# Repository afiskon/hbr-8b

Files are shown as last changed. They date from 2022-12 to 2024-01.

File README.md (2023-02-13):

# HBR/8B

All HF bands QRP CW transceiver. This is an improved version of [HBR/3B](https://github.com/afiskon/hbr-3b).

* Covers 80, 40, 30, 20, 17, 15, 12 and 10 meters
* Classical single IF superheterodyne design
* Has just a few barely hearable (~S0) spurious signals
* Simple but effective AGC
* Supports RIT and XIT
* 10-30 WPM Elekey-B type keyer + straight key mode
* Keyer supports record and playback, programmable with paddles
* ~5W class C power amplifier
* Has a S-meter and a SWR meter
* Open-source firmware, schematic and 3D-printable enclosure

Links:

* Article (in Russian): https://eax.me/hbr-8b-transceiver/
* Demo: https://www.youtube.com/watch?v=GlcS9r8nLz4

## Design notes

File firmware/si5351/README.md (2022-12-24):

# stm32-si5351

HAL-based Si5351 driver for STM32.

Main respository: https://github.com/afiskon/stm32-si5351

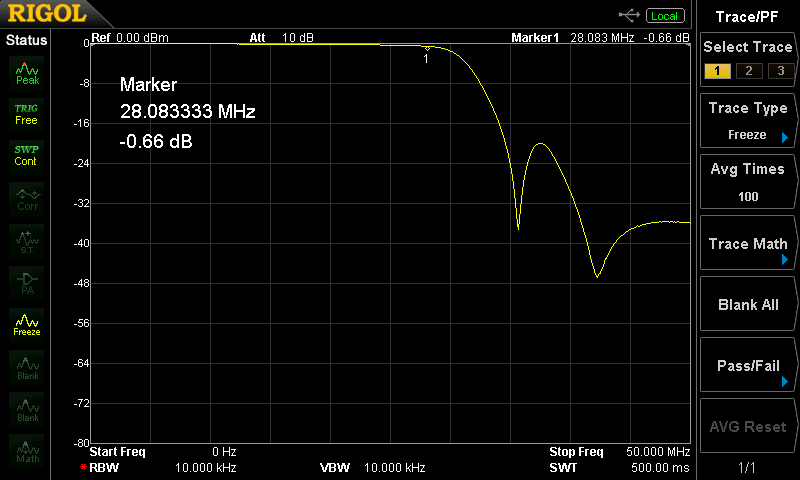
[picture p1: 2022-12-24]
images/lpfs/lpf-151210.png

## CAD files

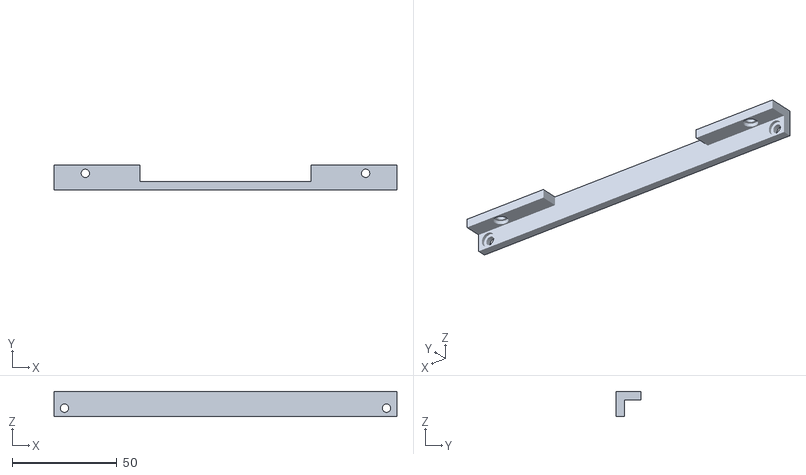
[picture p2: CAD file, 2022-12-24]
enclosure/large-angle.stl
164.0 x 12.0 x 12.0

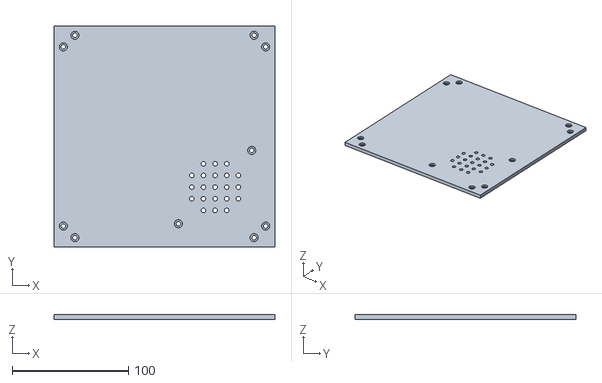
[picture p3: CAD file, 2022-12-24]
enclosure/top.stl
190.0 x 190.0 x 4.00

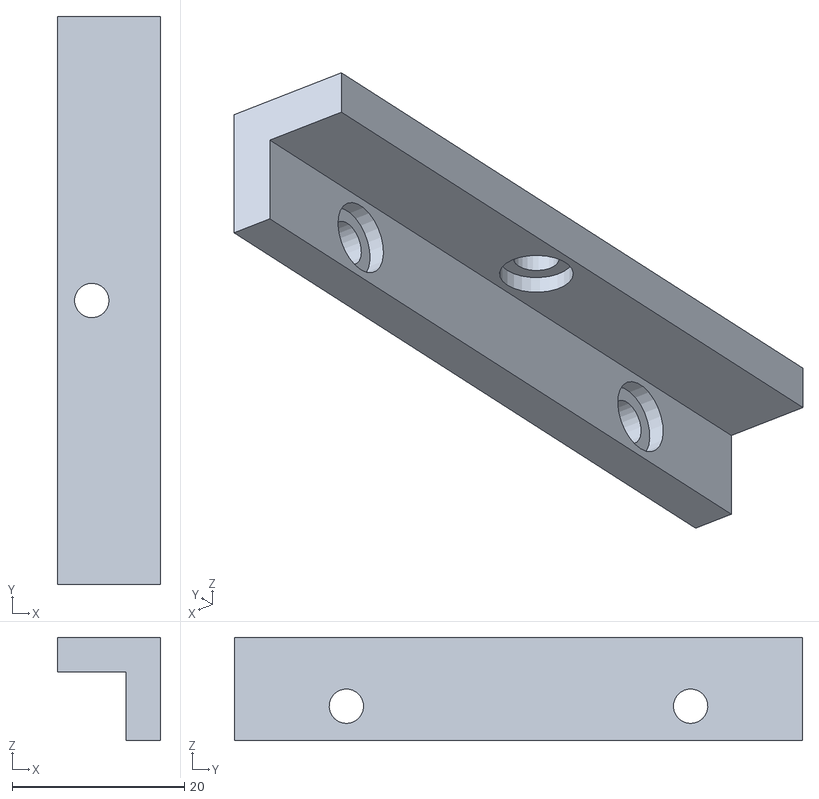
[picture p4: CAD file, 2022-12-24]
enclosure/small-angle.stl
12.0 x 66.0 x 12.0

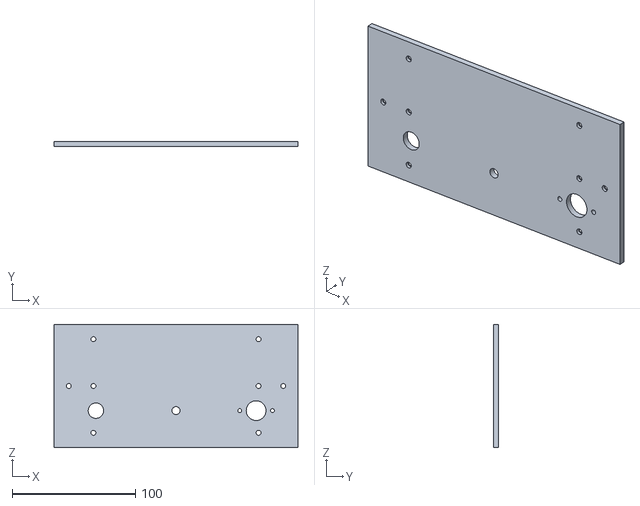
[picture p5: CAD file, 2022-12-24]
enclosure/back.stl
198.0 x 4.00 x 100.0

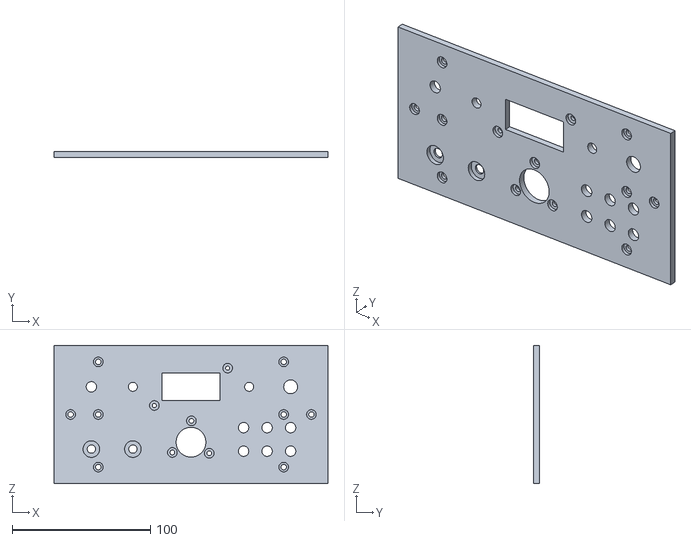
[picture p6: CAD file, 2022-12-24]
enclosure/front.stl
198.0 x 4.00 x 100.0

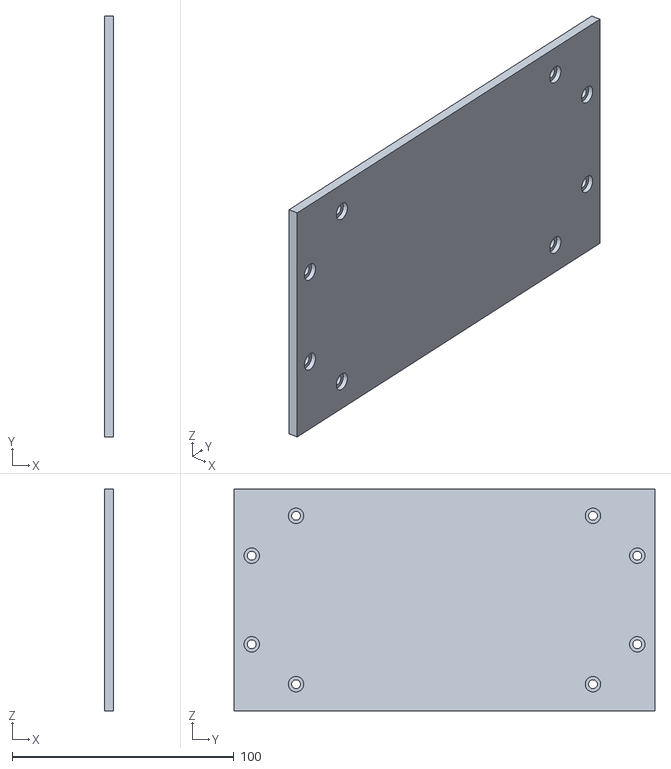
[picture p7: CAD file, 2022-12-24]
enclosure/side.stl
4.00 x 190.0 x 100.0

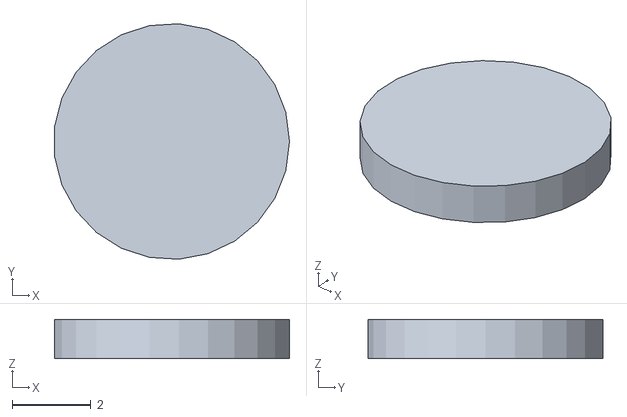
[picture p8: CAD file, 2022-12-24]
enclosure/screw-cap.stl
5.98 x 5.99 x 1.00

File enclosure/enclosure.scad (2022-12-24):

t = 4;
W = 190;
Front_W = W + t*2;
H = 100;

Angle_W = 12;
Large_Angle_L = W - 2*Angle_W - 2;
Small_Angle_L = H - 2*t - 2*Angle_W - 2;

Speaker_Dist_Between_Holes = 63;

pot_dia = 7+0.5; // volume control
jack_dia = 6; // 3.5 mm jack
jack_nut_dia = 12;
jack_nut_height = t-1.2;
button_dia = 7+0.5; // button
button_offset = 17;
toggle_dia = 6+0.5; // toggle switch
corner_dia = 7;
screw_dia = 4;
screw_offset = t*3;
screw_extra_offset = 20;
screw2_dia = 7;
screw2_height = 2;
nut_dia = 6.5;
nut_height = 1.5;
eps = 0.01;

main_enc_dia = 21+0.5;
main_enc_screws_dia = 15;
main_enc_screws_dist = 7;
main_enc_rotate_delta = 12;
main_enc_screw_dia = 3.5;
multi_enc_dia = 10;

// LCD info
LCD_W = 58;
LCD_H = 32;
lcd_offset_y = 8;
lcd_offset_x = 6;
lcd_h = LCD_H - lcd_offset_x*2;
lcd_w = LCD_W - lcd_offset_y*2;

hole_dia = 3;
hole_offset_x = 1+hole_dia/2;
hole_offset_y = 1+hole_dia/2;

module so239() { // two holes
    front_d = 16;
    front_off = 18.8;
    front_hole_d = 3.2;

    rotate([0, 45, 0]) {
        translate([0, 0, 0]) rotate([90,0,0])
            cylinder(d=front_d,h=20, $fn=100, center=true);

        translate([-front_off/2, 0, -front_off/2]) rotate([90,0,0])
            cylinder(d=front_hole_d,h=20,$fn=100, center=true);

        translate([front_off/2, 0, front_off/2]) rotate([90,0,0])
            cylinder(d=front_hole_d,h=20,$fn=100, center=true);
    }
}

module speaker() {
    union() {
        translate([Speaker_Dist_Between_Holes/2, -Speaker_Dist_Between_Holes/2, 0]) {
            cylinder(d = screw_dia, h = 20, $fn = 20, center = true);
            translate([0, 0, -(t-screw2_height)/2-eps])
                cylinder(d = screw2_dia, h = screw2_height+eps, $fn = 25, center = true);
        }
                
        translate([-Speaker_Dist_Between_Holes/2, Speaker_Dist_Between_Holes/2, 0]) {
            cylinder(d = screw_dia, h = 20, $fn = 20, center = true);
            translate([0, 0, -(t-screw2_height)/2-eps])
                cylinder(d = screw2_dia, h = screw2_height+eps, $fn = 25, center = true);
        }
                
        translate([10, 20, 0]) cylinder(d = screw_dia, h = 20, $fn = 20, center = true);
        translate([0, 20, 0]) cylinder(d = screw_dia, h = 20, $fn = 20, center = true);
        translate([-10, 20, 0]) cylinder(d = screw_dia, h = 20, $fn = 20, center = true);
        
        translate([10, 10, 0]) cylinder(d = screw_dia, h = 20, $fn = 20, center = true);
        translate([10, 0, 0]) cylinder(d = screw_dia, h = 20, $fn = 20, center = true);
        translate([10, -10, 0]) cylinder(d = screw_dia, h = 20, $fn = 20, center = true);
        
        translate([20, 10, 0]) cylinder(d = screw_dia, h = 20, $fn = 20, center = true);
        translate([20, 0, 0]) cylinder(d = screw_dia, h = 20, $fn = 20, center = true);
        translate([20, -10, 0]) cylinder(d = screw_dia, h = 20, $fn = 20, center = true);

        translate([0, 0, 0]) cylinder(d = screw_dia, h = 20, $fn = 200, center = true);
        translate([0, -10, 0]) cylinder(d = screw_dia, h = 20, $fn = 20, center = true);
        translate([0, 10, 0]) cylinder(d = screw_dia, h = 20, $fn = 20, center = true);
        
        translate([-10, 10, 0]) cylinder(d = screw_dia, h = 20, $fn = 20, center = true);
        translate([-10, 0, 0]) cylinder(d = screw_dia, h = 20, $fn = 20, center = true);
        translate([-10, -10, 0]) cylinder(d = screw_dia, h = 20, $fn = 20, center = true);
        
        translate([-20, 10, 0]) cylinder(d = screw_dia, h = 20, $fn = 20, center = true);
        translate([-20, 0, 0]) cylinder(d = screw_dia, h = 20, $fn = 20, center = true);
        translate([-20, -10, 0]) cylinder(d = screw_dia, h = 20, $fn = 20, center = true); 
        
        translate([10, -20, 0]) cylinder(d = screw_dia, h = 20, $fn = 20, center = true);
        translate([0, -20, 0]) cylinder(d = screw_dia, h = 20, $fn = 20, center = true);
        translate([-10, -20, 0]) cylinder(d = screw_dia, h = 20, $fn = 20, center = true);
    }
}

module front_back_base() {
    difference() {
       cube([Front_W, H, t], center = true);
        
        // screws
        translate([-Front_W/2+screw_offset+screw_extra_offset, H/2-screw_offset, 0]) {
            cylinder(d = screw_dia, h = t*2, $fn = 25, center = true);
            translate([0, 0, (t-screw2_height)/2+eps])
                cylinder(d = screw2_dia, h = screw2_height+eps, $fn = 25, center = true);
        } 
        
        translate([-Front_W/2+screw_offset+screw_extra_offset, -H/2+screw_offset, 0]) {
            cylinder(d = screw_dia, h = t*2, $fn = 25, center = true);
            translate([0, 0, (t-screw2_height)/2+eps])
                cylinder(d = screw2_dia, h = screw2_height+eps, $fn = 25, center = true);
        }
        
        translate([Front_W/2-screw_offset-screw_extra_offset, H/2-screw_offset, 0]) {
            cylinder(d = screw_dia, h = t*2, $fn = 25, center = true);
            translate([0, 0, (t-screw2_height)/2+eps])
                cylinder(d = screw2_dia, h = screw2_height+eps, $fn = 25, center = true);
        }
        
        translate([Front_W/2-screw_offset-screw_extra_offset, -H/2+screw_offset, 0]) {
            cylinder(d = screw_dia, h = t*2, $fn = 25, center = true);
            translate([0, 0, (t-screw2_height)/2+eps])
                cylinder(d = screw2_dia, h = screw2_height+eps, $fn = 25, center = true);
        }
        
        // center screws
       translate([-Front_W/2+screw_offset, 0, 0]) {
            cylinder(d = screw_dia, h = t*2, $fn = 25, center = true);
            translate([0, 0, (t-screw2_height)/2+eps])
                cylinder(d = screw2_dia, h = screw2_height+eps, $fn = 25, center = true);
        }
        translate([-Front_W/2+screw_offset+screw_extra_offset, 0, 0]) {
            cylinder(d = screw_dia, h = t*2, $fn = 25, center = true);
            translate([0, 0, (t-screw2_height)/2+eps])
                cylinder(d = screw2_dia, h = screw2_height+eps, $fn = 25, center = true);
        }
        translate([Front_W/2-screw_offset-screw_extra_offset, 0, 0]) {
            cylinder(d = screw_dia, h = t*2, $fn = 25, center = true);
            translate([0, 0, (t-screw2_height)/2+eps])
                cylinder(d = screw2_dia, h = screw2_height+eps, $fn = 25, center = true);
        }
        translate([Front_W/2-screw_offset, 0, 0]) {
            cylinder(d = screw_dia, h = t*2, $fn = 25, center = true);
            translate([0, 0, (t-screw2_height)/2+eps])
                cylinder(d = screw2_dia, h = screw2_height+eps, $fn = 25, center = true);
        } 
    }
}
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

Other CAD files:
enclosure/bottom.stl
enclosure/screw-cap.scad

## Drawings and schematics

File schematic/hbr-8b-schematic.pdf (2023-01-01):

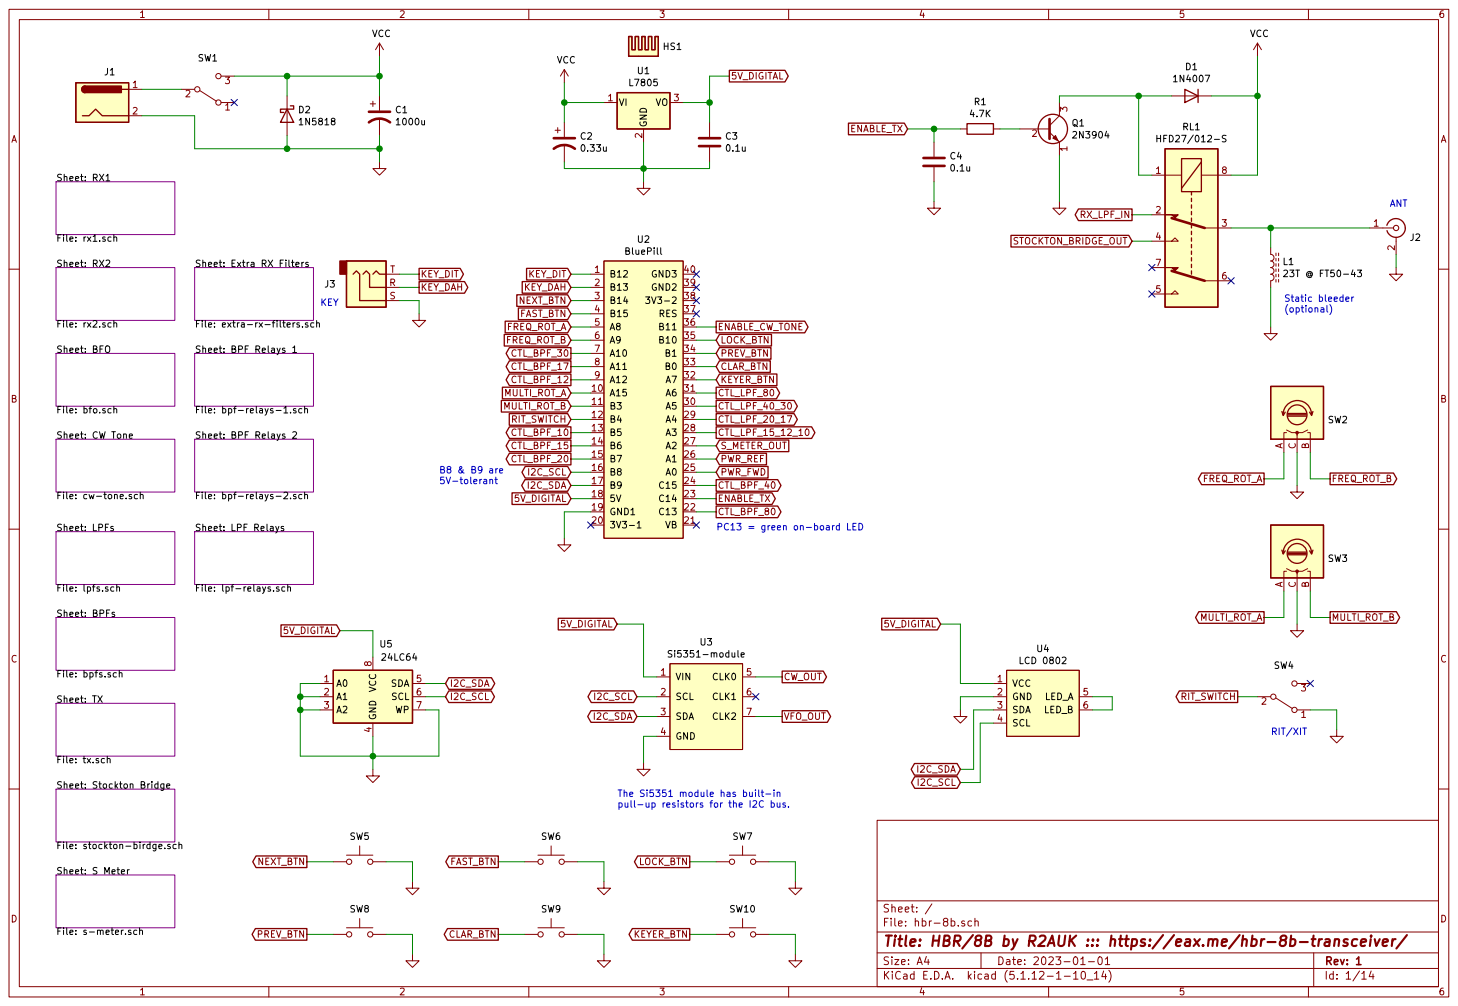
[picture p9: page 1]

File: bpf-relays-1.sch

File: bpf-relays-2.sch

Id: 1/14 Title: HBR/8B by R2AUK ::: https://eax.me/hbr-8b-transceiver/ File: hbr-8b.sch Sheet: / Sheet: LPFs File: lpfs.sch Sheet: BPFs File: bpfs.sch

PC13 = green on-board LED

File: lpf-relays.sch Sheet: S Meter File: s-meter.sch Sheet: Stockton Bridge

4 SDA 5 SCL 6 WP 7 VCC

File: stockton-birdge.sch Sheet: TX

pull-up resistors for the I2C bus.

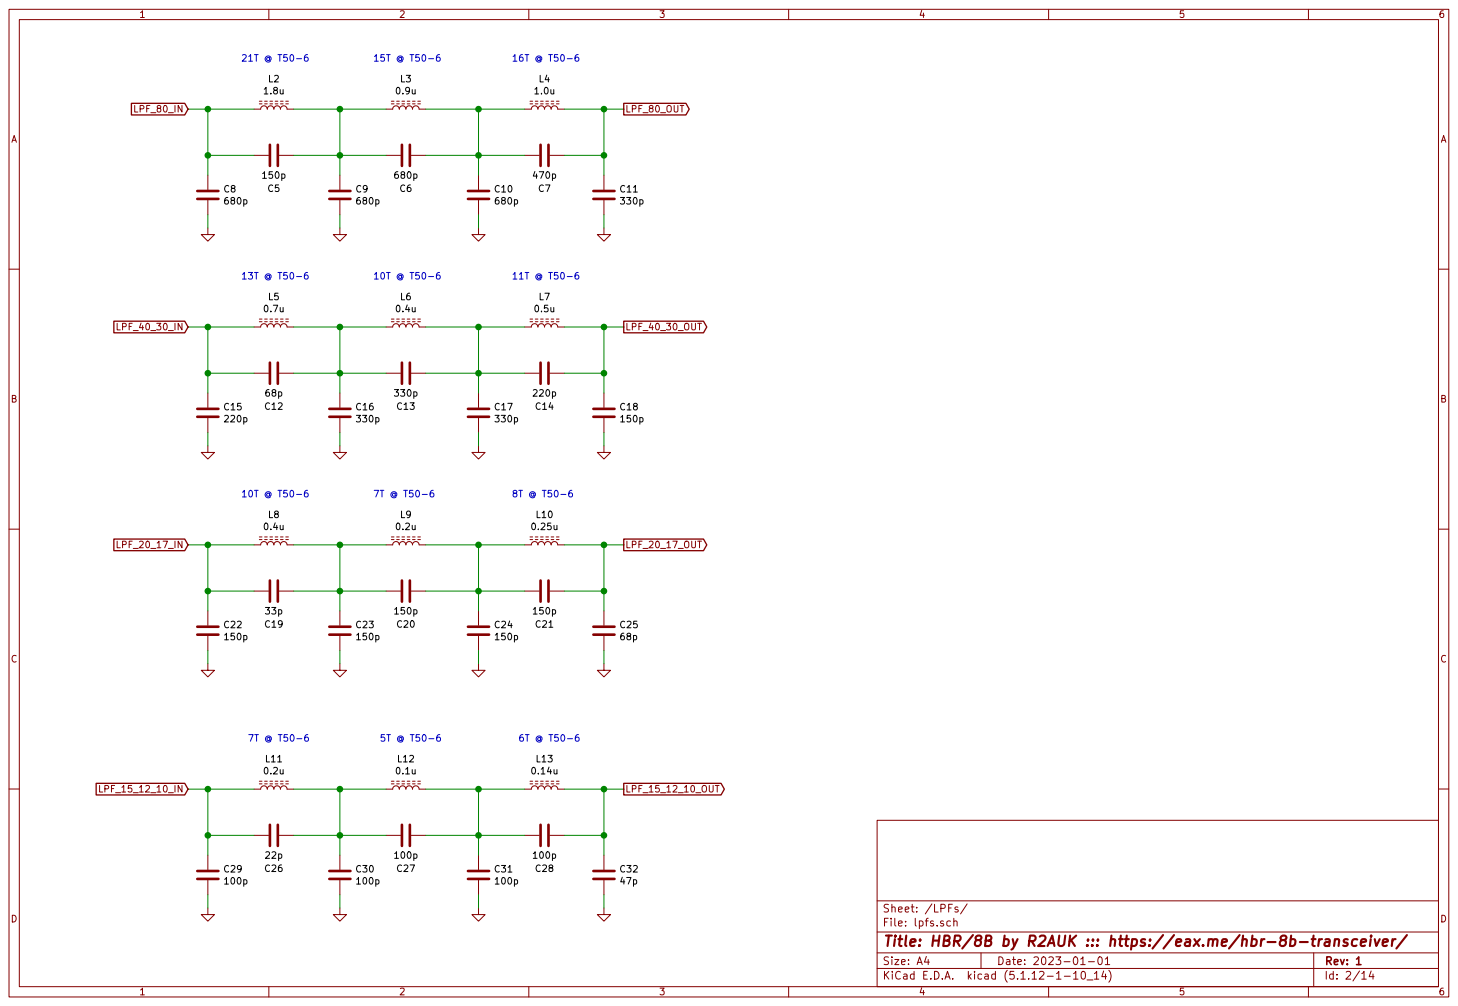
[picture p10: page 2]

File: lpfs.sch Sheet: /LPFs/ L11

Id: 2/14 Title: HBR/8B by R2AUK ::: https://eax.me/hbr-8b-transceiver/

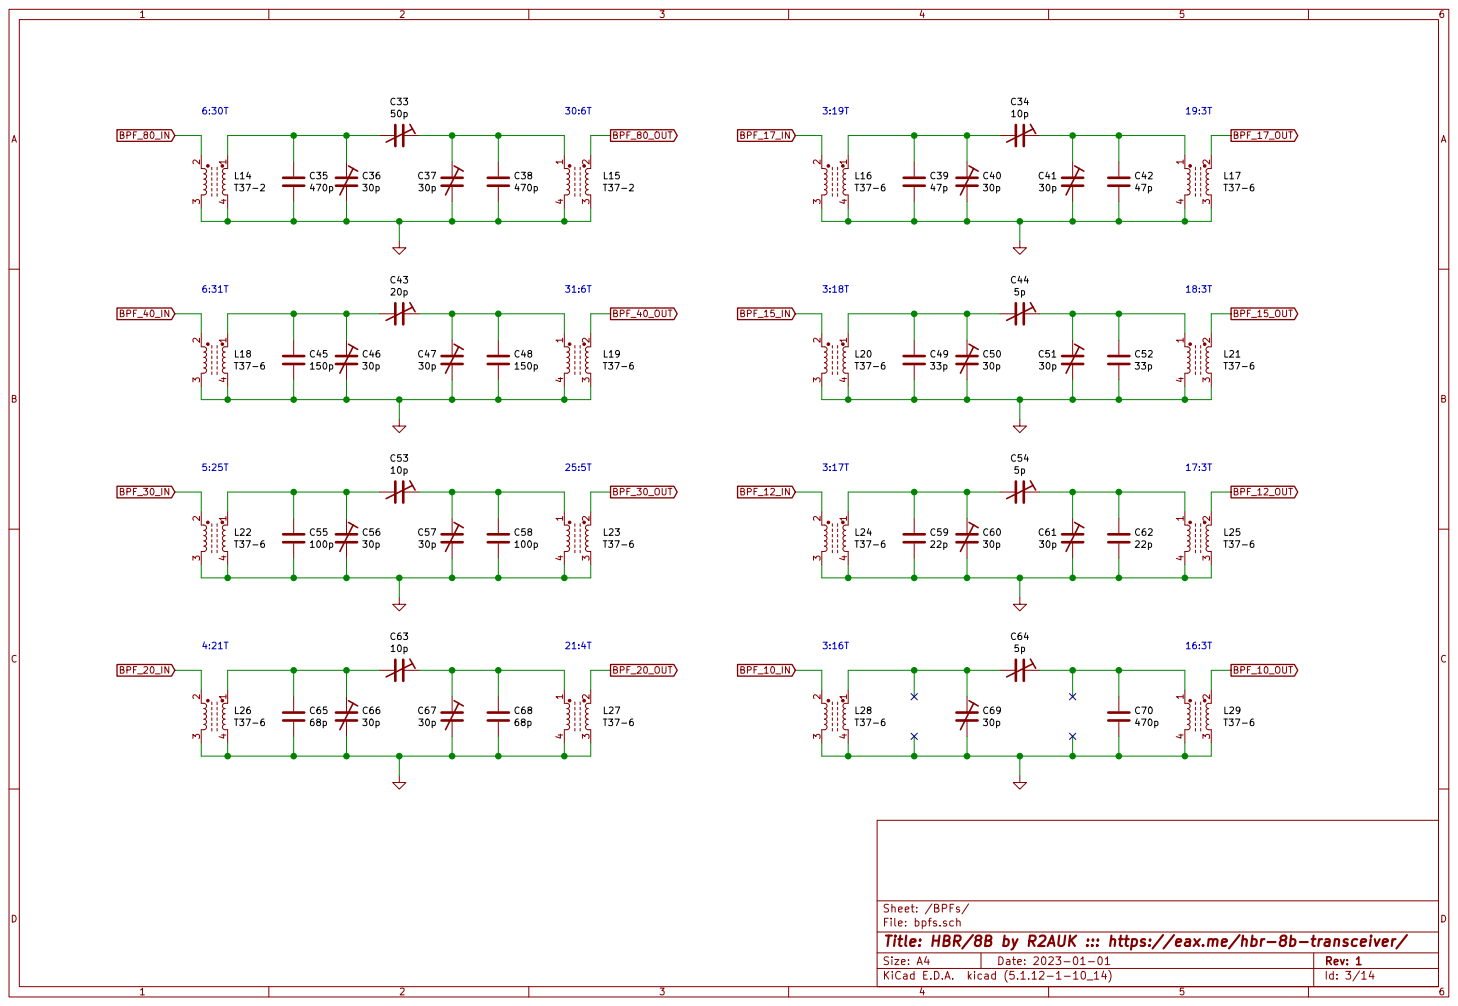
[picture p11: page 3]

File: bpfs.sch Sheet: /BPFs/
Id: 3/14 Title: HBR/8B by R2AUK ::: https://eax.me/hbr-8b-transceiver/

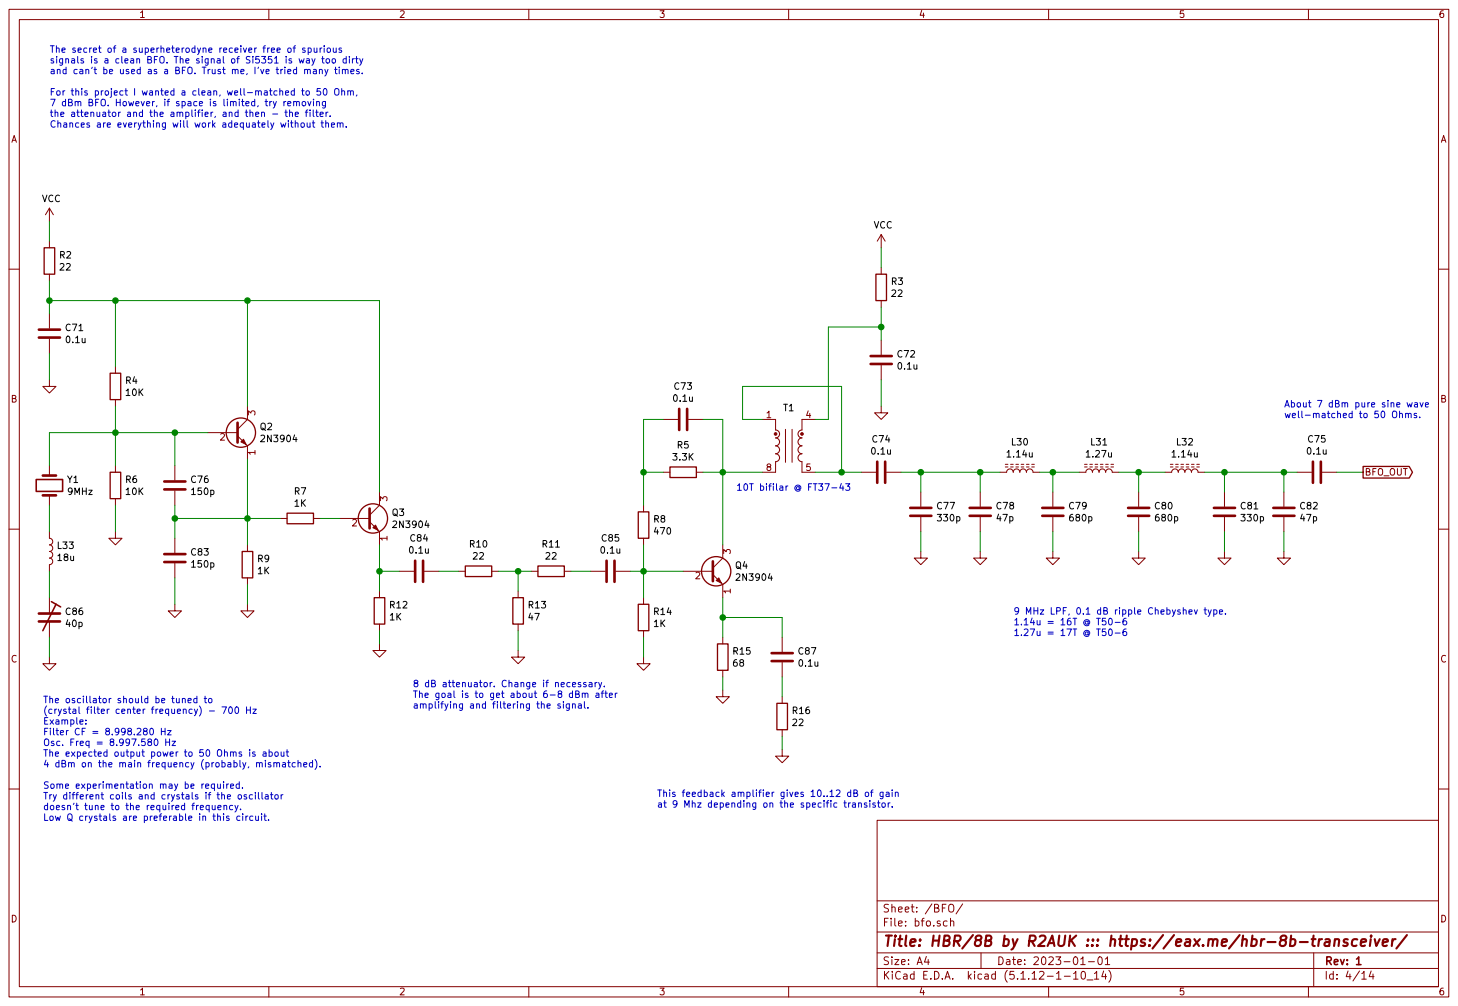
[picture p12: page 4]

signals is a clean BFO. The signal of Si5351 is way too dirty
and cant be used as a BFO. Trust me, Ive tried many times.

For this project I wanted a clean, well-matched to 50 Ohm,
7 dBm BFO. However, if space is limited, try removing
the attenuator and the amplifier, and then - the filter.
Chances are everything will work adequately without them.

10T bifilar @ FT37-43 This feedback amplifier gives 10..12 dB of gain

9 MHz LPF, 0.1 dB ripple Chebyshev type. 1.14u = 16T @ T50-6

8 dB attenuator. Change if necessary.
The goal is to get about 6-8 dBm after
amplifying and filtering the signal.

at 9 Mhz depending on the specific transistor. The oscillator should be tuned to
(crystal filter center frequency) - 700 Hz
Example: Filter CF = 8.998.280 Hz Osc. Freq = 8.997.580 Hz

The expected output power to 50 Ohms is about
4 dBm on the main frequency (probably, mismatched).

Some experimentation may be required.
Try different coils and crystals if the oscillator
doesnt tune to the required frequency.
Low Q crystals are preferable in this circuit.

Id: 4/14 Title: HBR/8B by R2AUK ::: https://eax.me/hbr-8b-transceiver/ File: bfo.sch Sheet: /BFO/

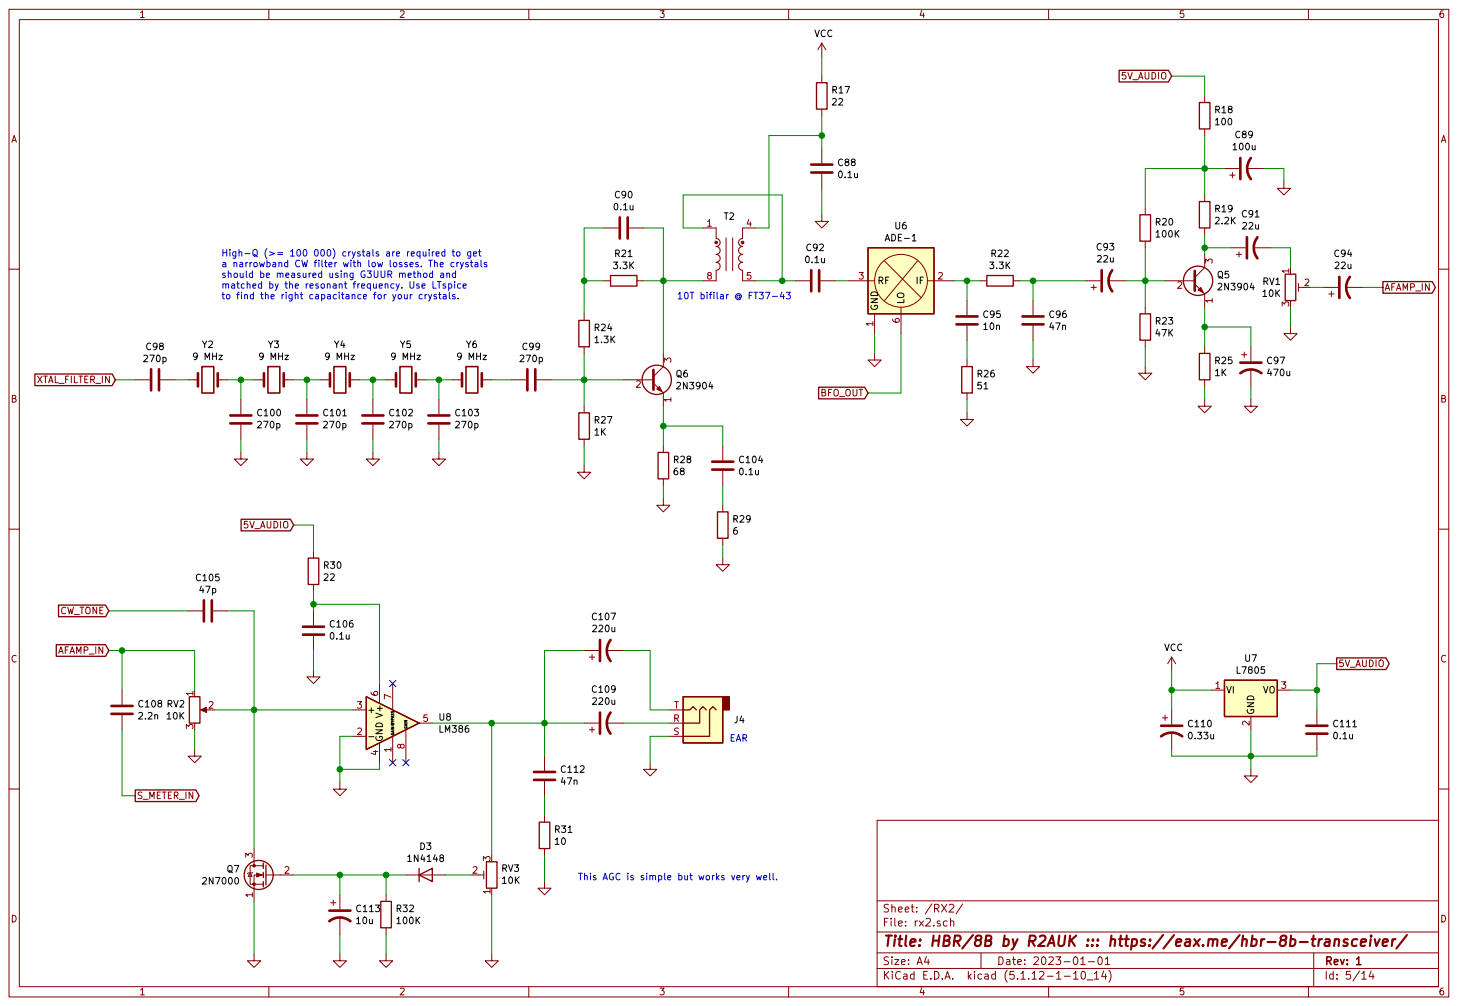
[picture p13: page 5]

VCC
10T bifilar @ FT37-43 This AGC is simple but works very well.

a narrowband CW filter with low losses. The crystals
should be measured using G3UUR method and
matched by the resonant frequency. Use LTspice

Id: 5/14 Title: HBR/8B by R2AUK ::: https://eax.me/hbr-8b-transceiver/ File: rx2.sch Sheet: /RX2/

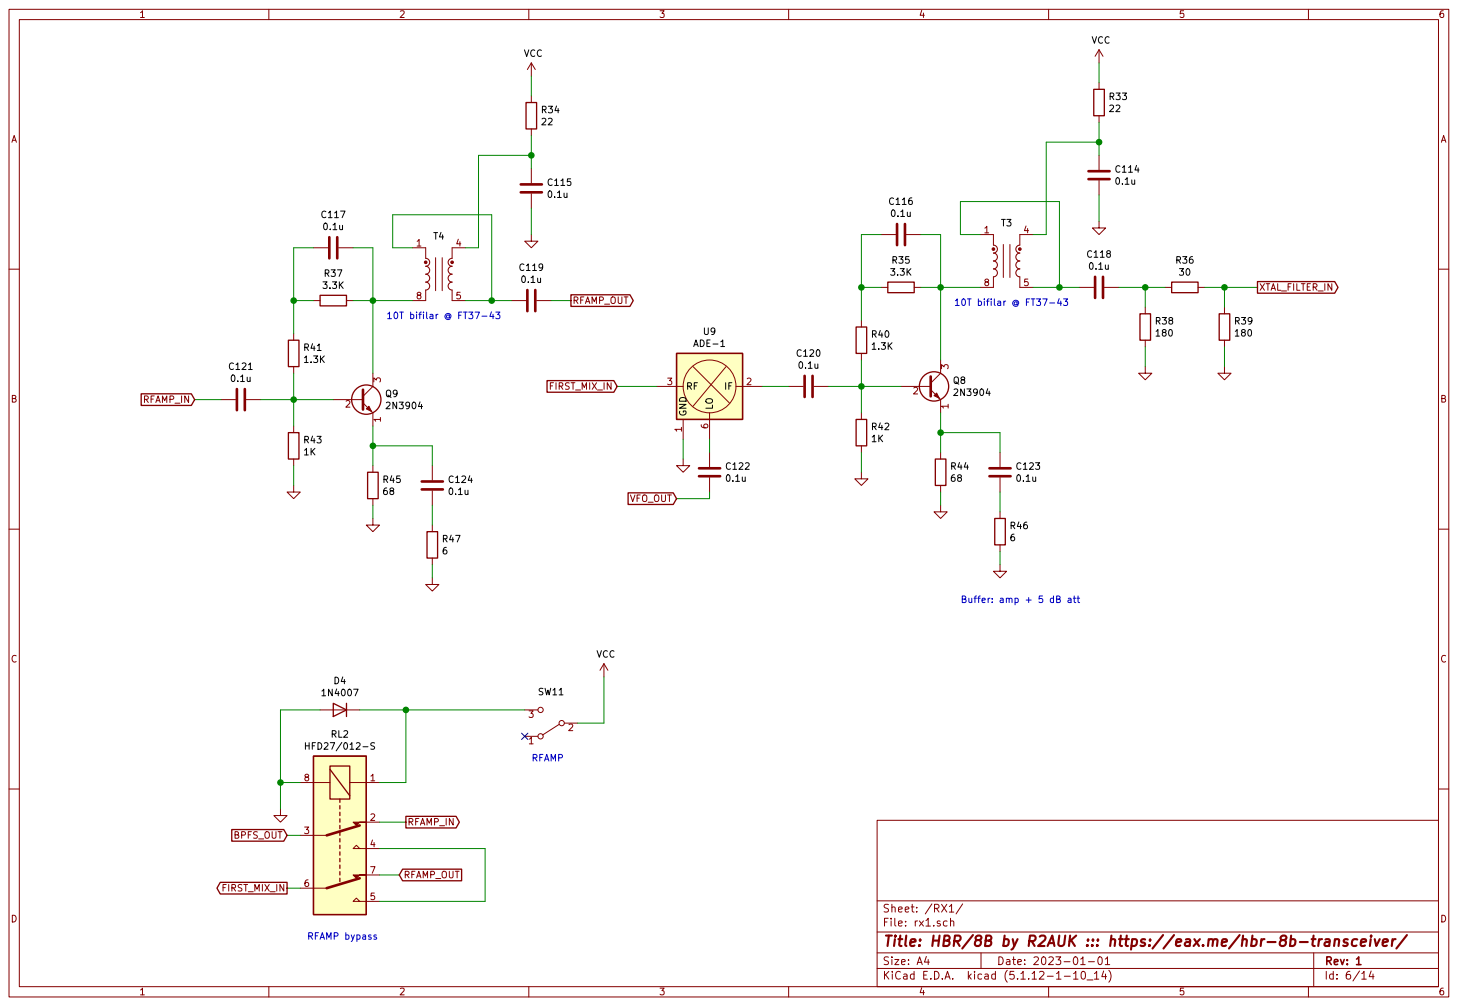
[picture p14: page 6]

Buffer: amp + 5 dB att RFAMP

Id: 6/14 Title: HBR/8B by R2AUK ::: https://eax.me/hbr-8b-transceiver/ File: rx1.sch Sheet: /RX1/

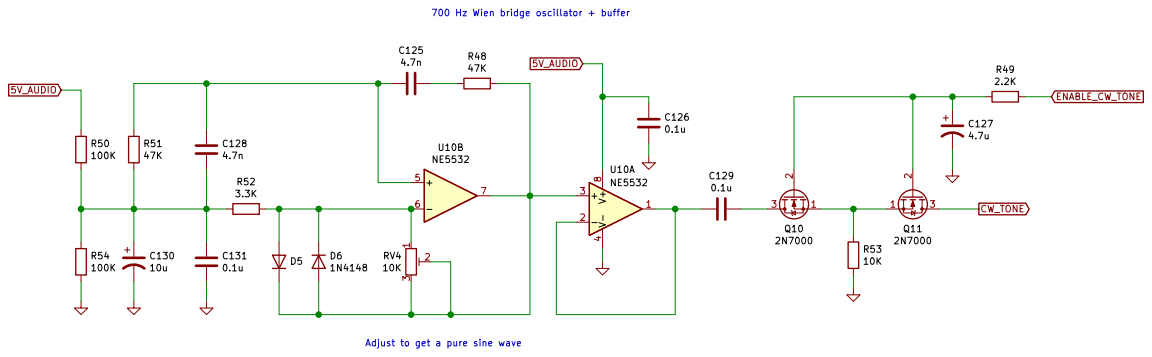
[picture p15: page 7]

700 Hz Wien bridge oscillator + buffer

Adjust to get a pure sine wave

Id: 7/14 Title: HBR/8B by R2AUK ::: https://eax.me/hbr-8b-transceiver/ File: cw-tone.sch Sheet: /CW Tone/

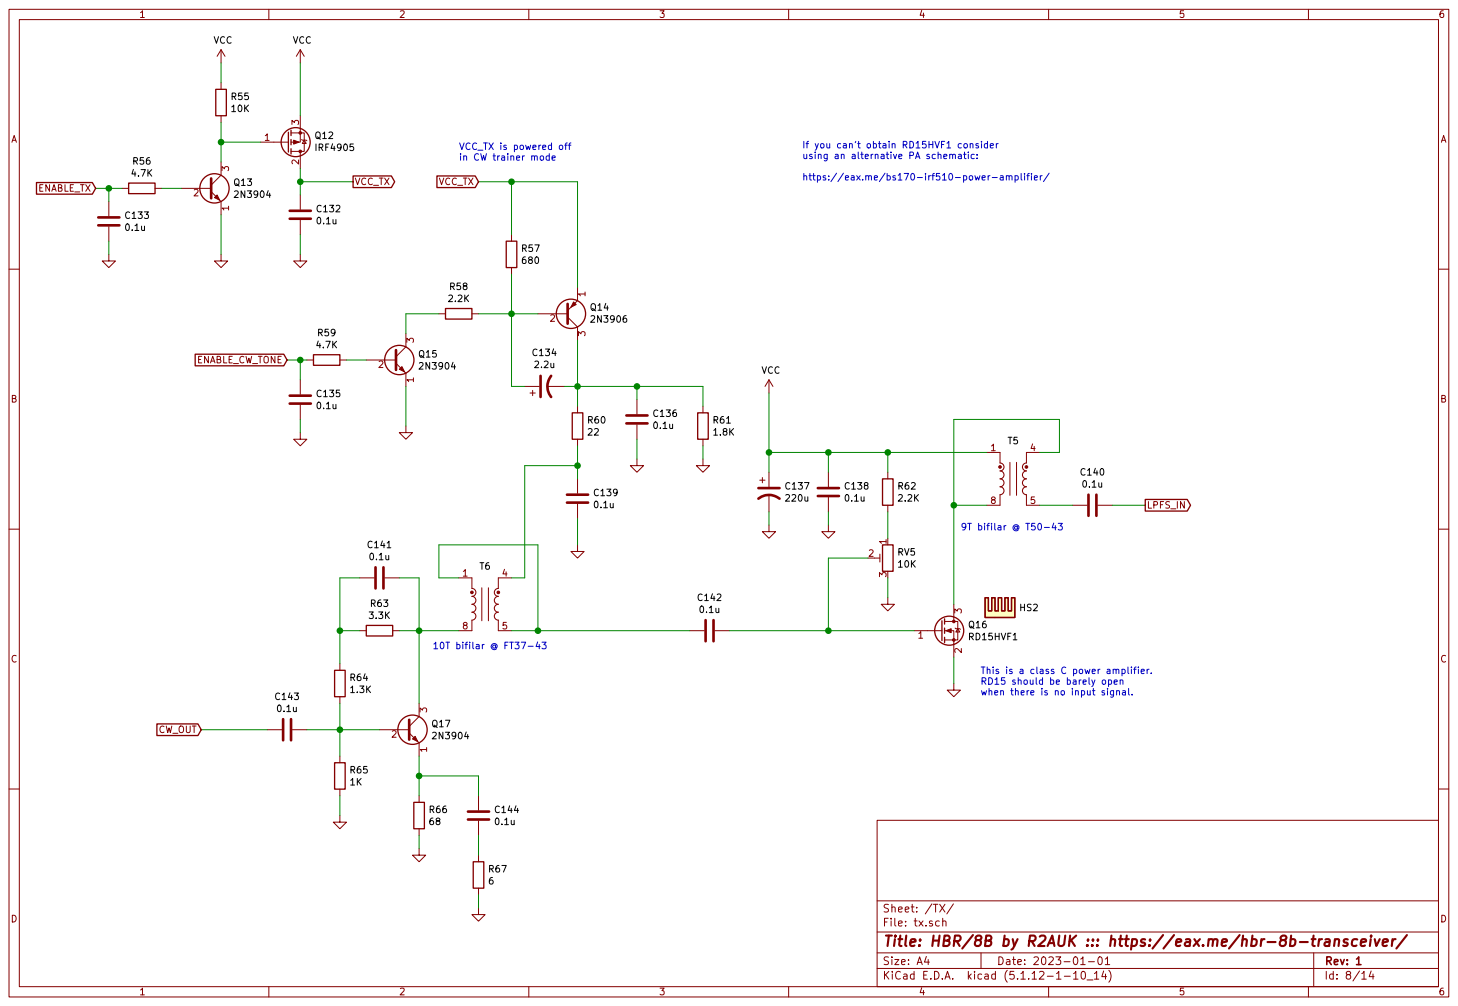
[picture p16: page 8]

VCC_TX is powered off
in CW trainer mode

If you cant obtain RD15HVF1 consider
using an alternative PA schematic:

https://eax.me/bs170-irf510-power-amplifier/

9T bifilar @ T50-43 This is a class C power amplifier.

when there is no input signal. 10T bifilar @ FT37-43

RD15 should be barely open

Id: 8/14 Title: HBR/8B by R2AUK ::: https://eax.me/hbr-8b-transceiver/ File: tx.sch Sheet: /TX/

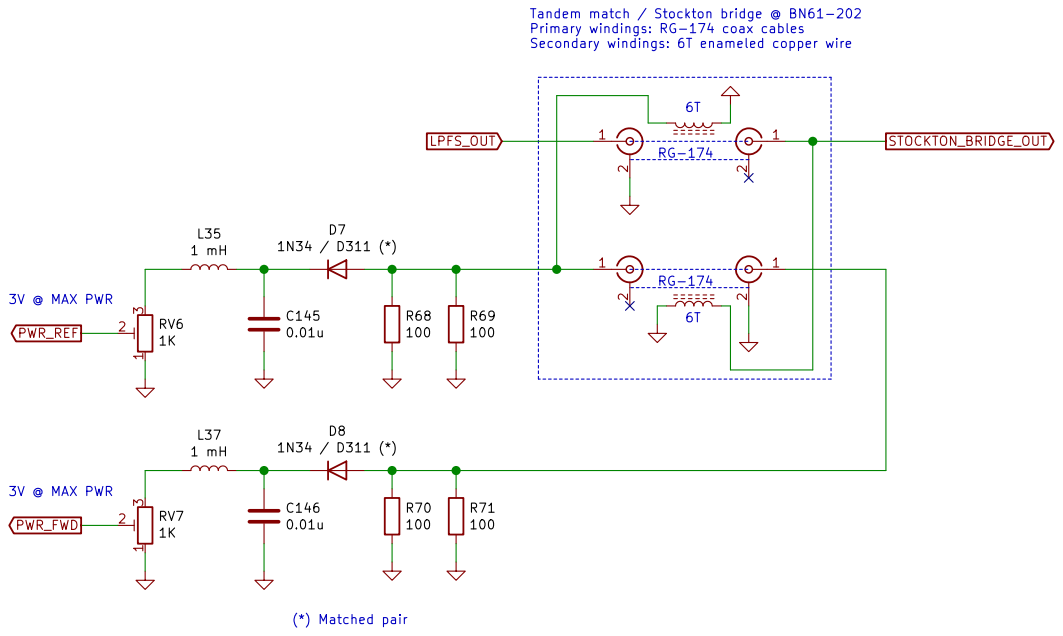
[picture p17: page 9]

Tandem match / Stockton bridge @ BN61-202
Primary windings: RG-174 coax cables
Secondary windings: 6T enameled copper wire

Sheet: /Stockton Bridge/
File: stockton-birdge.sch
Id: 9/14 Title: HBR/8B by R2AUK ::: https://eax.me/hbr-8b-transceiver/

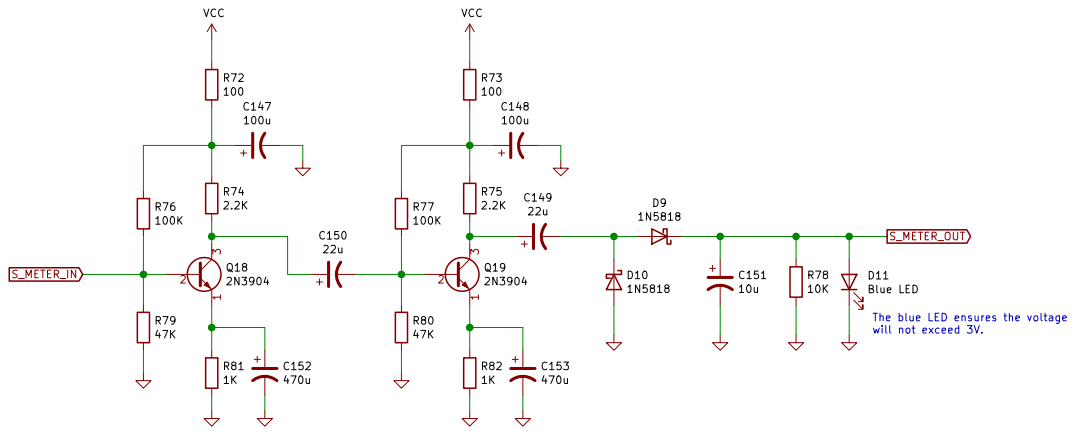
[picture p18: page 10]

The blue LED ensures the voltage will not exceed 3V.

Id: 10/14 Title: HBR/8B by R2AUK ::: https://eax.me/hbr-8b-transceiver/ File: s-meter.sch Sheet: /S Meter/

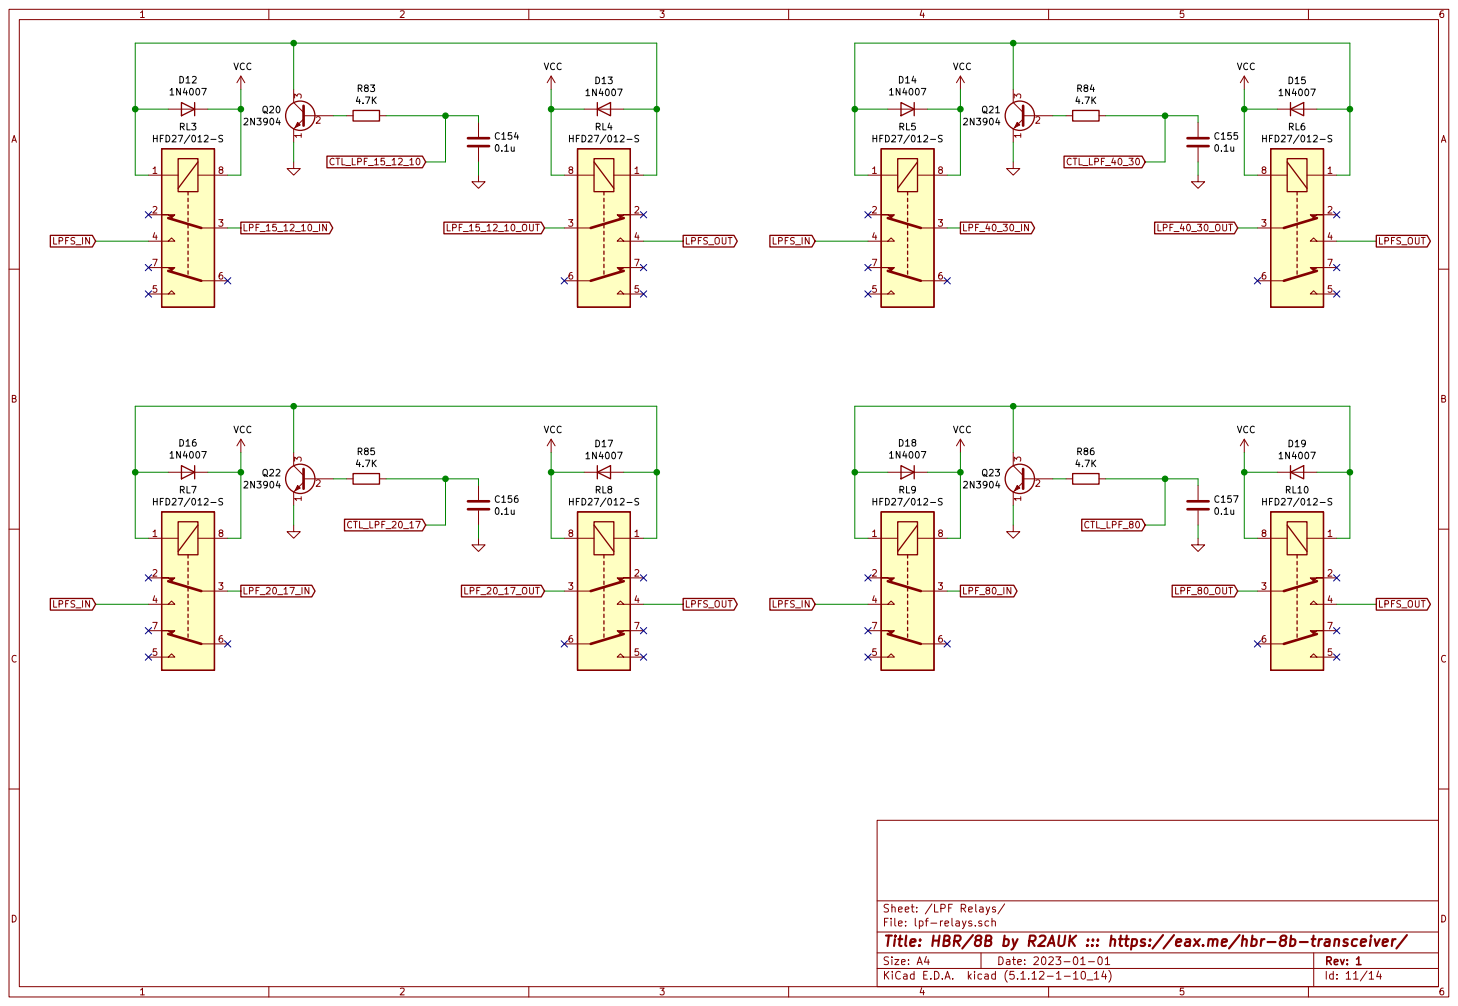
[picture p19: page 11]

Sheet: /LPF Relays/
File: lpf-relays.sch
Id: 11/14 Title: HBR/8B by R2AUK ::: https://eax.me/hbr-8b-transceiver/

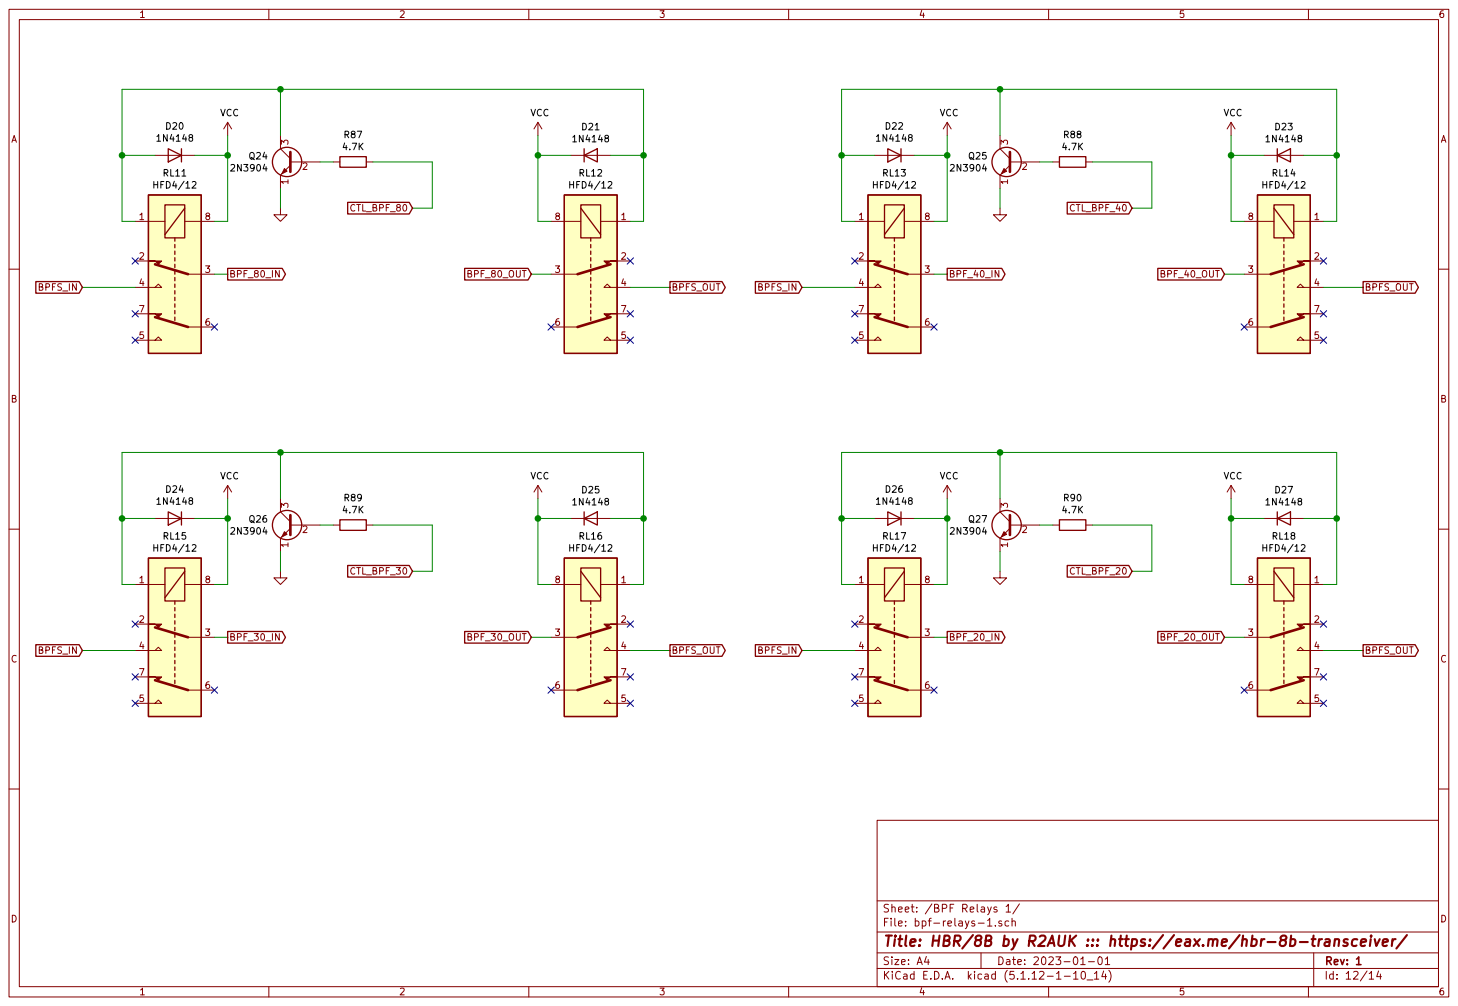
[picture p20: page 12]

Sheet: /BPF Relays 1/
File: bpf-relays-1.sch
Id: 12/14 Title: HBR/8B by R2AUK ::: https://eax.me/hbr-8b-transceiver/


Sheet: /BPF Relays 2/
File: bpf-relays-2.sch
Id: 13/14 Title: HBR/8B by R2AUK ::: https://eax.me/hbr-8b-transceiver/


These filters are not 100% mandatory
but they improve IMRR significantly.

31 MHz Chebyshev LPF, 1 dB ripple

0.3u = 9T @ T37-6 Some extra notch filters are recommended as well. For 80 meters one is not needed becasue the BPF has a very good suppression of potentially problematic

frequencies (21.5 MHz, 28.5 MHz) For 20-10 meters the RX LPF will do the trick. Tune to 25 MHz

Id: 14/14 Title: HBR/8B by R2AUK ::: https://eax.me/hbr-8b-transceiver/ File: extra-rx-filters.sch Sheet: /Extra RX Filters/

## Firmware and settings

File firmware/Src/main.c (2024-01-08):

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

/* Includes ------------------------------------------------------------------*/
#include "main.h"

/* USER CODE BEGIN Includes */
#include <string.h>
#include <stdlib.h>
#include <stdbool.h>
#include <math.h>
#include "si5351.h"
#include "lcd.h"

/* USER CODE END Includes */

ADC_HandleTypeDef hadc1;

I2C_HandleTypeDef hi2c1;

TIM_HandleTypeDef htim1;
TIM_HandleTypeDef htim2;

/* USER CODE BEGIN PV */

/* USER CODE END PV */

void SystemClock_Config(void);
static void MX_GPIO_Init(void);
static void MX_TIM1_Init(void);
static void MX_I2C1_Init(void);
static void MX_TIM2_Init(void);
static void MX_ADC1_Init(void);
/* USER CODE BEGIN PFP */

/* USER CODE END PFP */

/* USER CODE BEGIN 0 */

#define CH_CW   0
#define CH_CAL  1
#define CH_VFO  2

const int32_t XtalFilterCenterFrequency = 8998280;
const int32_t si5351_correction = 5760;

/* Adjust for used rotary encoders */
#define MAIN_DELTA_DIV 20
#define MAIN_DELTA_MULT 1
#define MULTI_DELTA_DIV 1
#define MULTI_DELTA_MULT -1

int32_t Fvfo = 1000000; // dummy value, will be changed below

const uint8_t eeprom_i2c_addr = (0x50 << 1);
#define EEPROM_PAGE_SIZE 32
#define KEYER_CONFIG_EEPROM_ADDR        0x0000
#define KEYER_MESSAGE_EEPROM_ADDR       0x0400

typedef enum {
    CLAR_MODE_DISABLED = 0,
    CLAR_MODE_RIT = 1,
    CLAR_MODE_XIT = 2,
} ClarMode_t;

bool lockMode = false;
bool fastMode = false;
ClarMode_t clarMode = CLAR_MODE_DISABLED;

int32_t clarOffset = 0;

typedef enum {
    CW_SEND_NONE = 0,
    CW_SEND_DIT = 1,
    CW_SEND_DAH = 2,
} CwSend_t;

CwSend_t lastSent = CW_SEND_NONE;
CwSend_t nextSend = CW_SEND_NONE;

typedef enum {
    KEYER_SETINGS_PAGE_SPEED = 0,
    KEYER_SETINGS_PAGE_XMIT = 1,
    KEYER_SETINGS_PAGE_SAVE = 2,
    KEYER_SETINGS_PAGE_PLAY = 3,
} KeyerSettingsPage_t;

typedef struct {
    uint16_t checksum;
    bool straightKey;
    int32_t speedWPM;
    int32_t ditTimeMs;
    KeyerSettingsPage_t settingsPage;
} KeyerConfig_t;

KeyerConfig_t keyerConfig = {
    .checksum = 0,
    .straightKey = false,
    .speedWPM = 19,

    // ditTimeMs = 60*1000/(50*WPM)
    // where 50 is the length in dits of "PARIS "
    // see https://morsecode.world/international/timing.html
    .ditTimeMs = 63,
    .settingsPage = KEYER_SETINGS_PAGE_SPEED,
};

#define MAX_KEYER_MESSAGE_LENGTH 500

typedef struct {
    uint16_t checksum;
    uint16_t length;
    char message[MAX_KEYER_MESSAGE_LENGTH];
} KeyerMessage_t;

KeyerMessage_t keyerMessage = {
    .checksum = 0,
    .length = 0,
};

bool inTransmitMode = false;

#define BUTTON_DEBOUNCE_TIME_MS 200
typedef enum {
    BUTTON_STATUS_PRESSED = 0,
    BUTTON_STATUS_RELEASED = 1,
    BUTTON_STATUS_DEBOUNCE = 2,
} ButtonStatus_t;

typedef enum {
    USE_LPF_80 = 0,
    USE_LPF_40_30 = 1,
    USE_LPF_20_17 = 2,
    USE_LPF_15_12_10 = 3,
} UseLPF_t;

typedef enum {
    USE_BPF_NONE = -1,
    USE_BPF_80 = 0,
    USE_BPF_40 = 1,
    USE_BPF_30 = 2,
    USE_BPF_20 = 3,
    USE_BPF_17 = 4,
    USE_BPF_15 = 5,
    USE_BPF_12 = 6,
    USE_BPF_10 = 7,
} UseBPF_t;

typedef struct {
    int32_t minFreq;
    int32_t maxFreq;
    int32_t lastFreq;
    UseLPF_t lpf;
    UseBPF_t bpf;
    /*
     * Compensate for losses in RG-174, frequency response of the given
     * PA depending on the used transistor, imperfections of the LPFs, etc.
     */
    si5351DriveStrength_t txDriveStrength;
} BandInfo_t;

int32_t currentBand = 3; // default: 20m

BandInfo_t bands[] = {
    {
        .minFreq  = 3500000,
        .maxFreq  = 3570000,
        .lastFreq = 3560000,
        .lpf = USE_LPF_80,
        .bpf = USE_BPF_80,
        .txDriveStrength = SI5351_DRIVE_STRENGTH_2MA,
    },
    {
        .minFreq  = 7000000,
        .maxFreq  = 7040000,
        .lastFreq = 7030000,
        .lpf = USE_LPF_40_30,
        .bpf = USE_BPF_40,
        .txDriveStrength = SI5351_DRIVE_STRENGTH_2MA,
    },
    {
        .minFreq  = 10100000,
        .maxFreq  = 10130000,
        .lastFreq = 10116000,
        .lpf = USE_LPF_40_30,
        .bpf = USE_BPF_30,
        .txDriveStrength = SI5351_DRIVE_STRENGTH_2MA,
    },
    {
        .minFreq  = 14000000,
        .maxFreq  = 14070000,
        .lastFreq = 14060000,
        .lpf = USE_LPF_20_17,
        .bpf = USE_BPF_20,
        .txDriveStrength = SI5351_DRIVE_STRENGTH_2MA,
    },
    {
        .minFreq  = 18068000,
        .maxFreq  = 18095000,
        .lastFreq = 18086000,
        .lpf = USE_LPF_20_17,
        .bpf = USE_BPF_17,
        .txDriveStrength = SI5351_DRIVE_STRENGTH_2MA,
    },
    {
        .minFreq  = 21000000,
        .maxFreq  = 21070000,
        .lastFreq = 21060000,
        .lpf = USE_LPF_15_12_10,
        .bpf = USE_BPF_15,
        .txDriveStrength = SI5351_DRIVE_STRENGTH_2MA,
    },
    {
        .minFreq  = 24890000,
        .maxFreq  = 24915000,
        .lastFreq = 24906000,
        .lpf = USE_LPF_15_12_10,
        .bpf = USE_BPF_12,
        .txDriveStrength = SI5351_DRIVE_STRENGTH_2MA,
    },
    {
        .minFreq  = 28000000,
        .maxFreq  = 28070000,
        .lastFreq = 28060000,
        .lpf = USE_LPF_15_12_10,
        .bpf = USE_BPF_10,
        .txDriveStrength = SI5351_DRIVE_STRENGTH_2MA,
    },
};

void ADC_Select_Channel(uint32_t ch) {
    ADC_ChannelConfTypeDef conf = {
        .Channel = ch,
        .Rank = 1,
        .SamplingTime = ADC_SAMPLETIME_28CYCLES_5,
    };
    if (HAL_ADC_ConfigChannel(&hadc1, &conf) != HAL_OK) {
        Error_Handler();
    }
} 

double ADC_ReadVoltage(uint32_t ch) {
    ADC_Select_Channel(ch);
    HAL_ADC_PollForConversion(&hadc1, HAL_MAX_DELAY);
    return ((double)HAL_ADC_GetValue(&hadc1))*3.3/4096.0;
}

// http://en.wikipedia.org/wiki/Jenkins_hash_function
uint32_t jenkinsHash(const uint8_t *data, const size_t len) {
    uint32_t hash, i;
    for(hash = i = 0; i < len; ++i) {
        hash += data[i];
        hash += (hash << 10);
        hash ^= (hash >> 6);
    }
    hash += (hash << 3);
    hash ^= (hash >> 11);
    hash += (hash << 15);
    return hash;
}

void loadKeyerMessage() {
    HAL_StatusTypeDef status;
    uint16_t savedChecksum;
    KeyerMessage_t savedKeyerMessage;

    for(;;) {
        status = HAL_I2C_IsDeviceReady(&hi2c1, eeprom_i2c_addr, 3, HAL_MAX_DELAY);
        if(status == HAL_OK)
            break;
    }

    HAL_I2C_Mem_Read(&hi2c1, eeprom_i2c_addr, KEYER_MESSAGE_EEPROM_ADDR, I2C_MEMADD_SIZE_16BIT,
            (uint8_t*)&savedKeyerMessage, sizeof(savedKeyerMessage), HAL_MAX_DELAY);

    savedChecksum = savedKeyerMessage.checksum;
    savedKeyerMessage.checksum = 0;

    if((jenkinsHash((const uint8_t*)&savedKeyerMessage, sizeof(savedKeyerMessage)) & 0xFFFF) == savedChecksum) {
        keyerMessage = savedKeyerMessage;
    } else {
        LCD_Goto(0, 0);
        LCD_SendString("MSG HASH");
        LCD_Goto(1, 0);
        LCD_SendString(" ERROR! ");
        HAL_Delay(2000);
        LCD_Clear();
    }
}

void saveKeyerMessage() {
    HAL_StatusTypeDef status;
    uint16_t checksum;
    size_t bytes_to_write = sizeof(keyerMessage);
    uint8_t* struct_offset = (uint8_t*)&keyerMessage;
    uint16_t eeprom_addr = KEYER_MESSAGE_EEPROM_ADDR;

    keyerMessage.checksum = 0;
    checksum = (jenkinsHash((const uint8_t*)&keyerMessage, sizeof(keyerMessage)) & 0xFFFF);
    keyerMessage.checksum = checksum;

    // sizeof(keyerMessage) exceeds EEPROM_PAGE_SIZE
    // so we have to write it in batches
    while(bytes_to_write > 0) {
        size_t batch_size = bytes_to_write;
        if(batch_size > EEPROM_PAGE_SIZE) {
            batch_size = EEPROM_PAGE_SIZE;
        }

        for(;;) {
            status = HAL_I2C_IsDeviceReady(&hi2c1, eeprom_i2c_addr, 3, HAL_MAX_DELAY);
            if(status == HAL_OK)
                break;
        }

        HAL_I2C_Mem_Write(&hi2c1, eeprom_i2c_addr, eeprom_addr, I2C_MEMADD_SIZE_16BIT,
            struct_offset, batch_size, HAL_MAX_DELAY);

        bytes_to_write -= batch_size;
        struct_offset += batch_size;
        eeprom_addr += batch_size;
    }
}

void loadKeyerConfig() {
    HAL_StatusTypeDef status;
    uint16_t savedChecksum;
    KeyerConfig_t savedKeyerConfig;

    for(;;) {
        status = HAL_I2C_IsDeviceReady(&hi2c1, eeprom_i2c_addr, 3, HAL_MAX_DELAY);
        if(status == HAL_OK)
            break;
    }

    HAL_I2C_Mem_Read(&hi2c1, eeprom_i2c_addr, KEYER_CONFIG_EEPROM_ADDR, I2C_MEMADD_SIZE_16BIT,
        (uint8_t*)&savedKeyerConfig, sizeof(savedKeyerConfig), HAL_MAX_DELAY);

    savedChecksum = savedKeyerConfig.checksum;
    savedKeyerConfig.checksum = 0;

    if((jenkinsHash((const uint8_t*)&savedKeyerConfig, sizeof(savedKeyerConfig)) & 0xFFFF) == savedChecksum) {
        keyerConfig = savedKeyerConfig;
    } else {
        LCD_Goto(0, 0);
        LCD_SendString("CFG HASH");
        LCD_Goto(1, 0);
        LCD_SendString(" ERROR! ");
        HAL_Delay(2000);
        LCD_Clear();
    }
}

void saveKeyerConfig() {
    HAL_StatusTypeDef status;
    uint16_t checksum;
    keyerConfig.checksum = 0;

    checksum = (jenkinsHash((const uint8_t*)&keyerConfig, sizeof(keyerConfig)) & 0xFFFF);
    keyerConfig.checksum = checksum;

    for(;;) {
        status = HAL_I2C_IsDeviceReady(&hi2c1, eeprom_i2c_addr, 3, HAL_MAX_DELAY);
        if(status == HAL_OK)
            break;
    }

    HAL_I2C_Mem_Write(&hi2c1, eeprom_i2c_addr, KEYER_CONFIG_EEPROM_ADDR, I2C_MEMADD_SIZE_16BIT,
        (uint8_t*)&keyerConfig, sizeof(keyerConfig), HAL_MAX_DELAY);
}

void changeKeyerSpeed(int32_t delta) {
    keyerConfig.speedWPM += delta;
    if(keyerConfig.speedWPM < 10) {
        keyerConfig.speedWPM = 10;
        keyerConfig.straightKey = true;
        keyerConfig.ditTimeMs = 60*1000/(50*(10+1)); // as for 10 WPM
    } else {
        keyerConfig.straightKey = false;
        if(keyerConfig.speedWPM > 30) {
            keyerConfig.speedWPM = 30;
        }

        /* +1 compensates the signal rise/fall time */
        keyerConfig.ditTimeMs = 60*1000/(50*(keyerConfig.speedWPM + 1));
    }
}

void SetupCLK(uint8_t output, int32_t Fclk, si5351DriveStrength_t driveStrength) {
    static bool pllSetupDone = false;
    si5351PLLConfig_t pll_conf;
    si5351OutputConfig_t out_conf;

    si5351_Calc(Fclk, &pll_conf, &out_conf);
    if(!pllSetupDone) {
        si5351_SetupPLL(SI5351_PLL_A, &pll_conf);
        pllSetupDone = true;
    }
    si5351_SetupOutput(output, SI5351_PLL_A, driveStrength, &out_conf);
}

void enableTx(bool enable) {
    HAL_GPIO_WritePin(GPIOC, GPIO_PIN_14, enable ? GPIO_PIN_SET : GPIO_PIN_RESET);
}

void changeFrequency(int32_t delta, bool force) {
    static int32_t prevFvfo = 0;

    if((!force) && lockMode) {
        return;
    }

    if(fastMode) {
        delta *= 10;
    }
    bands[currentBand].lastFreq += 100*delta;
    if(fastMode && (delta != 0)) {
        bands[currentBand].lastFreq -= bands[currentBand].lastFreq % 1000;
    }

    if(bands[currentBand].lastFreq < bands[currentBand].minFreq) {
        bands[currentBand].lastFreq = bands[currentBand].minFreq;
    } else if(bands[currentBand].lastFreq > bands[currentBand].maxFreq) {
        bands[currentBand].lastFreq = bands[currentBand].maxFreq;
    }

    Fvfo = bands[currentBand].lastFreq + XtalFilterCenterFrequency;
    if(clarMode == CLAR_MODE_RIT) {
        Fvfo += clarOffset;
    }

    if(force || (Fvfo != prevFvfo)) {
        SetupCLK(CH_VFO, Fvfo, SI5351_DRIVE_STRENGTH_4MA);
    }

    prevFvfo = Fvfo;
}

void displayFrequency() {
    char buff[16];
    snprintf(buff, sizeof(buff), "%02ld.%03ld.%01ld",
        bands[currentBand].lastFreq / 1000000,
        (bands[currentBand].lastFreq % 1000000) / 1000,
        (bands[currentBand].lastFreq % 1000) / 100);

    LCD_Goto(0, 0);
    LCD_SendString(buff);
}

bool buttonDitPressed() {
    return (HAL_GPIO_ReadPin(GPIOB, GPIO_PIN_12) == GPIO_PIN_RESET);
}

bool buttonDahPressed() {
    return (HAL_GPIO_ReadPin(GPIOB, GPIO_PIN_13) == GPIO_PIN_RESET);
}

void displaySMeterOrMode(bool force) {
    static const char* prevSValue = NULL;
    static uint32_t lastSMeterUpdateTime = 0;
    // don't forget to add '-u _printf_float' to LDFLAGS
    char buff[16];

    if(force) {
        LCD_Goto(1, 0);
        if(fastMode) {
            LCD_SendString("= FAST =");
            return;
        } else if(lockMode) {
            LCD_SendString("= LOCK =");
            return;
        } else if(clarMode != CLAR_MODE_DISABLED) {
            snprintf(buff, sizeof(buff), "%s%s%04d",
                clarMode == CLAR_MODE_RIT ? "RIT" : "XIT",
                clarOffset < 0 ? "-" : "+",
                abs(clarOffset));
            LCD_SendString(buff);
            return;
        }
    }

    uint32_t tstamp = HAL_GetTick();
    if(force || (tstamp - lastSMeterUpdateTime > 500)) {
        const char* sValue = NULL;
        double voltage = ADC_ReadVoltage(ADC_CHANNEL_2);

        if(voltage <= 0.035) {
            sValue = "S0      ";
        } else if(voltage <= 0.04) {
            sValue = "S1      ";
        } else if(voltage <= 0.06) {
            sValue = "S2\x02     ";
        } else if(voltage <= 0.1) {
            sValue = "S3\x02     ";
        } else if(voltage <= 0.2) {
            sValue = "S4\x02\x03    ";
        } else if(voltage <= 0.5) {
            sValue = "S5\x02\x03    ";
        } else if(voltage <= 0.9) {
            sValue = "S6\x02\x03\x04   ";
        } else if(voltage <= 1.8) {
            sValue = "S7\x02\x03\x04\x05  ";
        } else if(voltage <= 2.2) {
            sValue = "S8\x02\x03\x04\x05\x06 ";
        } else if(voltage <= 2.65) {
            sValue = "S9\x02\x03\x04\x05\x06\x07";
        } else {
            sValue = "S+\x02\x03\x04\x05\x06\x07";
        }

        if(force || (prevSValue != sValue)) {
            // Don't re-render the S-meter if we are about to transmit
            if(!buttonDitPressed() && !buttonDahPressed()) {
                LCD_Goto(1, 0);
                LCD_SendString(sValue);
            }
        }

        prevSValue = sValue;
        lastSMeterUpdateTime = tstamp;
    }
}

void keyDown() {
    // CW tone ON
    HAL_GPIO_WritePin(GPIOB, GPIO_PIN_11, GPIO_PIN_SET);
}

void keyUp() {
    // CW tone OFF
    HAL_GPIO_WritePin(GPIOB, GPIO_PIN_11, GPIO_PIN_RESET);
}

void switchLPFs(UseLPF_t lpf) {
    HAL_GPIO_WritePin(GPIOA, GPIO_PIN_3, lpf == USE_LPF_15_12_10 ? GPIO_PIN_SET : GPIO_PIN_RESET);
    HAL_GPIO_WritePin(GPIOA, GPIO_PIN_4, lpf == USE_LPF_20_17 ? GPIO_PIN_SET : GPIO_PIN_RESET);
    HAL_GPIO_WritePin(GPIOA, GPIO_PIN_5, lpf == USE_LPF_40_30 ? GPIO_PIN_SET : GPIO_PIN_RESET);
    HAL_GPIO_WritePin(GPIOA, GPIO_PIN_6, lpf == USE_LPF_80 ? GPIO_PIN_SET : GPIO_PIN_RESET);
}

void switchBPFs(UseBPF_t bpf) {
    HAL_GPIO_WritePin(GPIOA, GPIO_PIN_10, bpf == USE_BPF_30 ? GPIO_PIN_SET : GPIO_PIN_RESET);
    HAL_GPIO_WritePin(GPIOA, GPIO_PIN_11, bpf == USE_BPF_17 ? GPIO_PIN_SET : GPIO_PIN_RESET);
    HAL_GPIO_WritePin(GPIOA, GPIO_PIN_12, bpf == USE_BPF_12 ? GPIO_PIN_SET : GPIO_PIN_RESET);

    HAL_GPIO_WritePin(GPIOB, GPIO_PIN_5, bpf == USE_BPF_10 ? GPIO_PIN_SET : GPIO_PIN_RESET);
    HAL_GPIO_WritePin(GPIOB, GPIO_PIN_6, bpf == USE_BPF_15 ? GPIO_PIN_SET : GPIO_PIN_RESET);
    HAL_GPIO_WritePin(GPIOB, GPIO_PIN_7, bpf == USE_BPF_20 ? GPIO_PIN_SET : GPIO_PIN_RESET);

    HAL_GPIO_WritePin(GPIOC, GPIO_PIN_13, bpf == USE_BPF_80 ? GPIO_PIN_SET : GPIO_PIN_RESET);
    HAL_GPIO_WritePin(GPIOC, GPIO_PIN_15, bpf == USE_BPF_40 ? GPIO_PIN_SET : GPIO_PIN_RESET);
}

void changeBand(int32_t delta) {
    currentBand += delta;
    while(currentBand < 0) {
        currentBand += sizeof(bands)/sizeof(bands[0]);
    }
    currentBand %= sizeof(bands)/sizeof(bands[0]);

    switchBPFs(bands[currentBand].bpf);
    switchLPFs(bands[currentBand].lpf);

    changeFrequency(0, false);
    si5351_EnableOutputs(1 << CH_VFO);
    displayFrequency();
}

void ensureTransmitMode() {
    if(inTransmitMode) {
        return;
    }

    int32_t targetFrequency = bands[currentBand].lastFreq;
    if(clarMode == CLAR_MODE_XIT) {
        targetFrequency += clarOffset;
    }

    SetupCLK(CH_CW, targetFrequency, bands[currentBand].txDriveStrength);
    si5351_EnableOutputs(1 << CH_CW);

    // Switch off the BPF. Otherwhise one can hear the signal being transmitted
    // despite the fact that VFO is disabled. The signal is very quiet but the
    // frequency is a bit off the built-in tone generator, so the tone sounds
    // a bit distorted.
    switchBPFs(USE_BPF_NONE);

    enableTx(true);

    LCD_Goto(1, 0);
    LCD_SendString("SWR  ---");

    inTransmitMode = true;
}

void ensureReceiveMode() {
    if(!inTransmitMode) {
        return;
    }
    enableTx(false);

    // Switch on the BPF
    switchBPFs(bands[currentBand].bpf);

    // Restore the original VFO
    changeFrequency(0, true);
    si5351_EnableOutputs(1 << CH_VFO);
    displaySMeterOrMode(true);
    inTransmitMode = false;
}

ButtonStatus_t buttonPressed(GPIO_TypeDef *GPIOx, uint16_t GPIO_Pin, uint32_t* lastPressed) {
    if(HAL_GPIO_ReadPin(GPIOx, GPIO_Pin) == GPIO_PIN_RESET) {
        uint32_t now = HAL_GetTick();
        if(now - *lastPressed > BUTTON_DEBOUNCE_TIME_MS) {
            *lastPressed = now;
            return BUTTON_STATUS_PRESSED;
        } else {
            return BUTTON_STATUS_DEBOUNCE;
        }
    }
    return BUTTON_STATUS_RELEASED;
}

bool switchRitMode() {
    return (HAL_GPIO_ReadPin(GPIOB, GPIO_PIN_4) == GPIO_PIN_RESET);
}

ButtonStatus_t buttonNextPressed() {
    static uint32_t lastPressed = 0;
    return buttonPressed(GPIOB, GPIO_PIN_14, &lastPressed);
}

ButtonStatus_t buttonPrevPressed() {
    static uint32_t lastPressed = 0;
    return buttonPressed(GPIOB, GPIO_PIN_1, &lastPressed);
}

ButtonStatus_t buttonFastPressed() {
    static uint32_t lastPressed = 0;
    return buttonPressed(GPIOB, GPIO_PIN_15, &lastPressed);
}

ButtonStatus_t buttonLockPressed() {
    static uint32_t lastPressed = 0;
    return buttonPressed(GPIOB, GPIO_PIN_10, &lastPressed);
}

ButtonStatus_t buttonClarPressed() {
    static uint32_t lastPressed = 0;
    return buttonPressed(GPIOB, GPIO_PIN_0, &lastPressed);
}

ButtonStatus_t buttonKeyerPressed() {
    static uint32_t lastPressed = 0;
    return buttonPressed(GPIOA, GPIO_PIN_7, &lastPressed);
}

// `straightKeyerKeyIsDown` is used to avoid calling keyUp()/keyDown() if we did it already.
// Calling HAL_GPIO_WritePin() too often generates a hearable noise.
bool straightKeyerKeyIsDown;

void initStraightKeyer() {
    straightKeyerKeyIsDown = false;
}

void processStraightKeyerLogic(bool pressed) {
    if(pressed) {
        if(!straightKeyerKeyIsDown) {
            keyDown();
            straightKeyerKeyIsDown = true;
        }
    } else if(straightKeyerKeyIsDown) {
        keyUp();
        straightKeyerKeyIsDown = false;
    }
}

void initIambicKeyer() {
    // iambic keyer has nothing to init
}

static size_t iambicKeyerLogOffset = 0;
static char iambicKeyerLog[MAX_KEYER_MESSAGE_LENGTH] = {0};

void iambicKeyerLogReset() {
    iambicKeyerLogOffset = 0;
}

size_t iambicKeyerLogSize() {
    return iambicKeyerLogOffset;
}

size_t iambicKeyerLogSpaceLeft() {
    return MAX_KEYER_MESSAGE_LENGTH - iambicKeyerLogOffset;
}

// Iambic keyer logs up to MAX_KEYER_MESSAGE_LENGTH symbols.
// '.' is a dit
// '-' is a dah
// ' ' is a pause between letters
// '/' is a pause between words
// Multiple pauses between letters are logged as one pause.
// Multiple pauses between words are also logged as one pause.
// Pauses in the beginning of the message are not logged.
void iambicKeyerLogEmit(char c) {
    if(iambicKeyerLogSpaceLeft() == 0) {
        // truncate the message if there is not space left in the buffer
        return;
    }

    if(((c == ' ') || (c == '/')) && (iambicKeyerLogOffset == 0)) {
        // don't log the pauses in the beginning of the message
        return;
    }

    if((c == ' ') && iambicKeyerLog[iambicKeyerLogOffset-1] == ' ') {
        // multiple pauses between letters are logged as one pause
        return;
    }

    if((c == '/') && iambicKeyerLog[iambicKeyerLogOffset-1] == '/') {
        // multiple pauses between words are logged as one pause.
        return;
    }

    if((c == '/') && iambicKeyerLog[iambicKeyerLogOffset-1] == ' ') {
        // previously logged pause between letters became a pause between words
        iambicKeyerLog[iambicKeyerLogOffset-1] = '/';
        return;
    }

    if((c == ' ') && iambicKeyerLog[iambicKeyerLogOffset-1] == '/') {
        // to my knowledge this should never happen...
        return;
    }

    // log the symbol
    iambicKeyerLog[iambicKeyerLogOffset] = c;
    iambicKeyerLogOffset++;
}
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
int main(void)
{
  /* MCU Configuration--------------------------------------------------------*/

  /* Reset of all peripherals, Initializes the Flash interface and the Systick. */
  HAL_Init();

  /* Configure the system clock */
  SystemClock_Config();

  /* Initialize all configured peripherals */
  MX_GPIO_Init();
  MX_TIM1_Init();
  MX_I2C1_Init();
  MX_TIM2_Init();
  MX_ADC1_Init();
  /* USER CODE BEGIN 2 */
  init();
  /* USER CODE END 2 */

  /* Infinite loop */
  /* USER CODE BEGIN WHILE */
  while (1)
  {
    loopMain();
    /* USER CODE END WHILE */

    /* USER CODE BEGIN 3 */

  }
  /* USER CODE END 3 */
}

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


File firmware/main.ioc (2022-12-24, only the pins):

Mcu.UserName=STM32F103C8Tx
PA0-WKUP.Signal=ADCx_IN0
PA1.Signal=ADCx_IN1
PA10.Signal=GPIO_Output
PA11.Signal=GPIO_Output
PA12.Signal=GPIO_Output
PA13.Signal=SYS_JTMS-SWDIO
PA14.Signal=SYS_JTCK-SWCLK
PA15.Signal=S_TIM2_CH1_ETR
PA2.Signal=ADCx_IN2
PA3.Signal=GPIO_Output
PA4.Signal=GPIO_Output
PA5.Signal=GPIO_Output
PA6.Signal=GPIO_Output
PA7.Signal=GPIO_Input
PA8.Signal=S_TIM1_CH1
PA9.Signal=S_TIM1_CH2
PB0.Signal=GPIO_Input
PB1.Signal=GPIO_Input
PB10.Signal=GPIO_Input
PB11.Signal=GPIO_Output
PB12.Signal=GPIO_Input
PB13.Signal=GPIO_Input
PB14.Signal=GPIO_Input
PB15.Signal=GPIO_Input
PB3.Signal=S_TIM2_CH2
PB4.Signal=GPIO_Input
PB5.Signal=GPIO_Output
PB6.Signal=GPIO_Output
PB7.Signal=GPIO_Output
PB8.Signal=I2C1_SCL
PB9.Signal=I2C1_SDA
PC13-TAMPER-RTC.Signal=GPIO_Output
PC14-OSC32_IN.Signal=GPIO_Output
PC15-OSC32_OUT.Signal=GPIO_Output
PD0-OSC_IN.Signal=RCC_OSC_IN
PD1-OSC_OUT.Signal=RCC_OSC_OUT

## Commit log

2022-12-24 Move the project from a sandbox repository
    [bfo.sch, bpf-relays-1.sch, bpf-relays-2.sch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]
2022-12-24 Copy enclosure/ from HBR/3B repository
    [back.stl, bottom.stl, enclosure.scad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]
2023-01-01 Add extra RX filters
    [bfo.sch, bpf-relays-1.sch, bpf-relays-2.sch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]
2024-01-03 Firmware: little bugfix + minor changes
    [main.c]

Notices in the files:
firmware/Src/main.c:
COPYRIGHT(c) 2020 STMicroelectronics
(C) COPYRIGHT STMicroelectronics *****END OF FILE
